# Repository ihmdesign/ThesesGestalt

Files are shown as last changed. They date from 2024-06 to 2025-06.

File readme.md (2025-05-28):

# **VibraForge: A Scalable Prototyping Toolkit For Creating Spatialized Vibrotactile Feedback Systems** #

This repository shares the open-source design files of the VibraForge toolkit, including mechanical design, electrical design, software design, and GUI editor. 

- Electrical Design
- GUI Editor
- Mechanical Design
- Software Design

If you are interested in using the toolkit and would like to get a development kit from us, please fill out [this Google Form](https://forms.gle/6aN7M9MWAf4sLqWE6)

## Quickstart Guidelines

If you already have the hardware dev kit shipped by the authors, it should contain a [quickstart guide](quickstart_guide.pdf) that you can easily follow.

Otherwise, you can follow step 1 & 2 to make the hardware yourself.

1. The `Electrical Design` folder has detailed descriptions of how to use the PCB design files to print the boards, and to program the boards with Arduino / MPLab X IDE.

2. The `Mechanical Design` folder contains all the CAD design files to print the parts.

3. Once all the hardware is setup, an easy place to start is to run the `Software_Design/Python_Server/Python_Test.py` program. It is used for simple test of the bluetooth control. You can manually input the vibration parameters in command lines. make sure the CHARACTERISTIC_UUID and CONTROL_UNIT_NAME are the same in control unit's Arduino code. To run the code:
```
Python Python_Test.py -uuid CUSTOM_UUID -name CONTROL_UNIT_NAME

default uuid = 'f22535de-5375-44bd-8ca9-d0ea9ff9e410'
default name = 'QT Py ESP32-S3'
```

4. If everything works well with `Python_Test.py`, then you can proceed to integrate the toolkit into your system! If you want to experiment with different vibration waveforms, you can use the `GUI_Editor` to try different waveforms, such as Sine, PWM, Triangle and Saw, etc. If you want to integrate the toolkit into Unity Engine developments, Use the `Software_design/Unity_Engine_API`. 

For detailed descriptions of each step, please refer to the `readme` files in the subfolders.

## Some Notes for Debugging

### Control Unit

Regarding the control unit, **the order of the four chain connectors** are shown in the figure. Also note that the USB port should be facing left. Putting it in the wrong direction may result in shorting the ESP32 MCU. 

If the MCU is not working for some unknown reasons, it might be a good idea to factory reset it following [this link](https://learn.adafruit.com/adafruit-qt-py-esp32-s3/factory-reset).

Control Unit Notes

### Vibration Unit

The unit address on each chain **starts from 0**. Maximum sixteen units can be connected to each chain. Therefore, the units on the first chain have address 0,1,2,...,15; The units on the second chain have address 16,17,...,31. When the programming pins are on the top, the input is on the left side, and the output is on the right side. Do not reverse the order, or the unit driver board might damage due to shortage.

Each vibration unit driver PCB has **two LEDs**. When the first LED lights up, it indicates that the board is correctly powered, when the second LED lights up, it indicates that it receives "Start" commands and should be vibrating. These two LEDs can be useful for checking MCU status during debugging.

Control Unit Notes

## Bug Report

If you identify any bug while using the toolkit, feel free to submit a new issue! The authors would try to resolve them ASAP :D

Have fun with the toolkit!

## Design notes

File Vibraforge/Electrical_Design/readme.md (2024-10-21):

# Electrical Engineering Section ##

The electrical engineering section includes PCB design files for control units and vibration units, and main programs for microcontrollers. All PCB design were initially finished in [EasyEDA](https://easyeda.com/) and later exported to different formats. If you want to manufacture the board with PCB factories such as [JLCPCB](https://jlcpcb.com/) or [PCBWay](https://www.pcbway.com/), simply use the Gerber files. If you want to revise the design, Import the design files into EasyEDA Editor or Altium Designer.

Control units include the large unit and the small unit, with different ESP32 microcontrollers. The large unit uses [Adafruit ESP32 Feather V2](https://learn.adafruit.com/adafruit-esp32-feather-v2). The small unit uses [Adafruit QT Py ESP32-S3](https://learn.adafruit.com/adafruit-qt-py-esp32-s3). The Arduino programs are very similar, except the software serial pins are configured differently.

Arduino Library Rrquirements:
- [Arduino ESP32 support](https://github.com/espressif/arduino-esp32)
- [SoftwareSerial for ESP32](https://github.com/plerup/espsoftwareserial)

Vibration units include LRA and VCA, all using the PIC16F18313 8-pin microcontroller. The main program is the same across all vibration units. To program / reprogram the MCU, you need to download the [MPLAB X IDE](https://www.microchip.com/en-us/tools-resources/develop/mplab-x-ide) and buy the  [MPLAB® PICkit™ 5 In-Circuit Debugger](https://www.microchip.com/en-us/development-tool/pg164150). import the main program into the IDE, connect the programming pins from the debugger to the top of the PCB board, following this [quickstart guideline](https://ww1.microchip.com/downloads/aemDocuments/documents/DEV/ProductDocuments/Brochures/MPLAB-PICkit-5-In-Circuit-Debugger-Quick-Start-Guide-50003478.pdf).

- Control_Unit
  - Large_Unit
  - Small_Unit
  - Main_Program_Arduino
    - BLE_peripheral_ESP32V2
    - BLE_peripheral_QTPyS3
- Vibration_Unit
  - Board_LRA
  - Board_VCA
  - Main_Program_MPLABXIDE
  - Schematic

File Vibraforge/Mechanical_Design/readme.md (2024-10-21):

# Mechanical Design

This folder contains CAD files for control units and vibration units. In our lab environment, parts are printed with PLA materials using 0.4mm nozzles on [Bambu Lab X1C 3D Printer](store.bambulab.com/collections/3d-printer/products/x1-carbon). Other printers with higher precision should also satisfy the requirements.

- Control_Unit_Large
- Control_Unit_Small
- Vibration_Unit_LRAX
- Vibration_Unit_LRAZ
- Vibration_Unit_VCA

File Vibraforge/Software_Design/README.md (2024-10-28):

# Software Design

## Python_Server

Python Lib Requirement:
- [BLEAK](https://bleak.readthedocs.io/en/latest/)

Three programs are available:
1. Python_Test.py

It is used for simple test of the bluetooth control. Users can manually input the vibration parameters in command lines. make sure the CHARACTERISTIC_UUID and CONTROL_UNIT_NAME are the same in control unit's Arduino code. To run the code:
```
Python Python_Test.py -uuid CUSTOM_UUID -name CONTROL_UNIT_NAME

default uuid = 'f22535de-5375-44bd-8ca9-d0ea9ff9e410'
default name = 'QT Py ESP32-S3'
```

2. Python_Play_Command.py

It reads commands from a data file, and plays vibrations accordingly. Data file are written in the following format:
```
{"time": 2.0, "addr": 1, "mode": 1, "duty": 0, "freq": 2}
{"time": 2.03, "addr": 1, "mode": 1, "duty": 1, "freq": 2}
{"time": 2.06, "addr": 1, "mode": 1, "duty": 2, "freq": 2}
```
To run the code:
```
Python Python_Play_Command.py -uuid CUSTOM_UUID -name CONTROL_UNIT_NAME -file FILENNAME

default uuid = 'f22535de-5375-44bd-8ca9-d0ea9ff9e410'
default name = 'QT Py ESP32-S3'
default file = 'command.json'
```

3. Python_Unity_Server.py

It receives vibration commands sent from Unity Engine through socket communication, converts the command format from JSON to bytearray, and sends the commands to the control unit. To run the code:

```
Python Python_Unity_Server.py -uuid CUSTOM_UUID -name CONTROL_UNIT_NAME -host HOST_IP -port PORT

default uuid = 'f22535de-5375-44bd-8ca9-d0ea9ff9e410'
default name = 'QT Py ESP32-S3'
default host = '127.0.0.1'
default port = 9051
```

## Unity_Engine_API

We also provide a Unity Engine API so that designers can directly make function calls to control vibrations. To get started, you can run the VibraForge_Plugin Unity project and see how the function calls are used to trigger vibrations when a ball collides with a wall. To integrate it into your own project,

1. Import `VibraForge_Plugin.unitypackage` as a custom package into an existing project.
2. Use the `VibraForgeSender` prefab to create a new gameobject, and configure the server IP address and port if needed. 
3. When Unity Engine events are triggered (e.g., OnTriggerEnter, OnTriggerExit, etc), call `VibraForge.SendCommand(addr, mode, duty, freq)` to send vibration commands.
4. Note: the `Python_Unity_Server.py` program is used to receive vibration commands through socket communication with Unity Engine APIs. it should be run before running the Unity program.

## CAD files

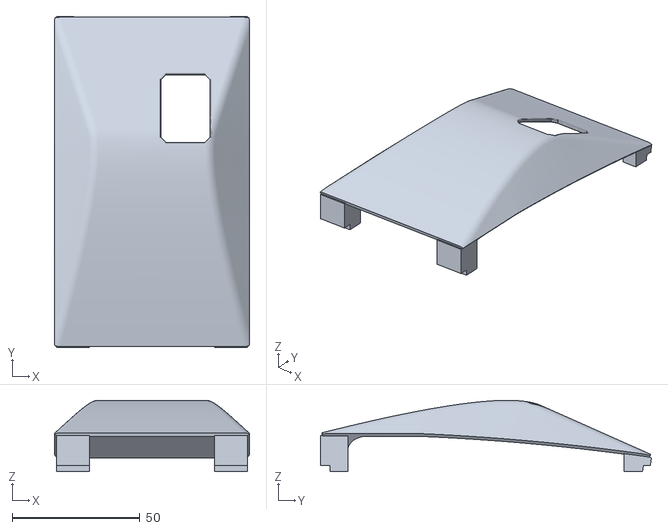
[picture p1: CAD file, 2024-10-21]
Vibraforge/Mechanical_Design/Control_Unit_Large/Cap.stl
76.4 x 129.4 x 27.9

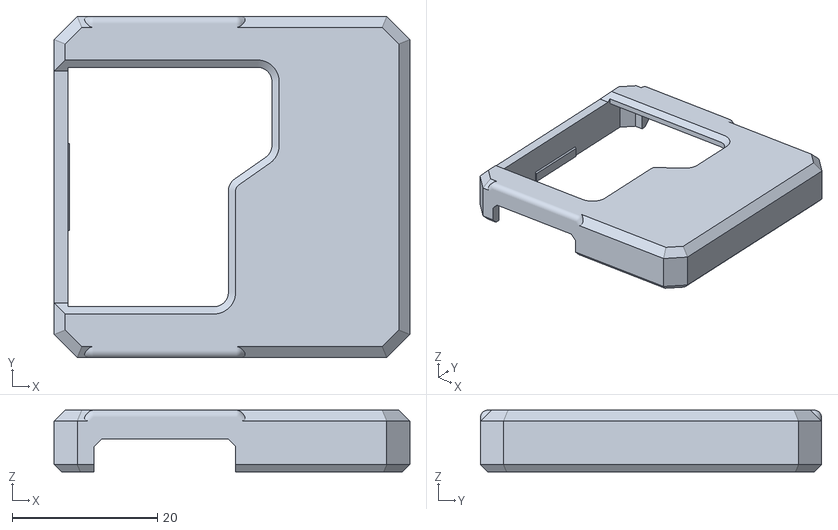
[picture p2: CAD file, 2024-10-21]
Vibraforge/Mechanical_Design/Control_Unit_Small/Cap.stl
49.0 x 47.0 x 8.50

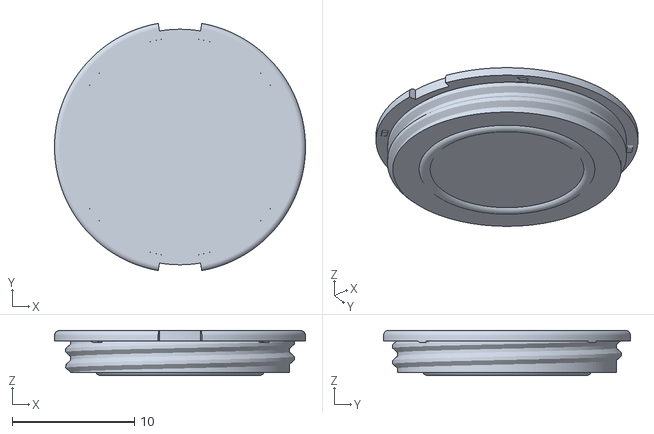
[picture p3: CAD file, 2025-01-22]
Vibraforge/Mechanical_Design/Vibration_Unit_LRAX/Cap.stl
20.5 x 20.2 x 3.70

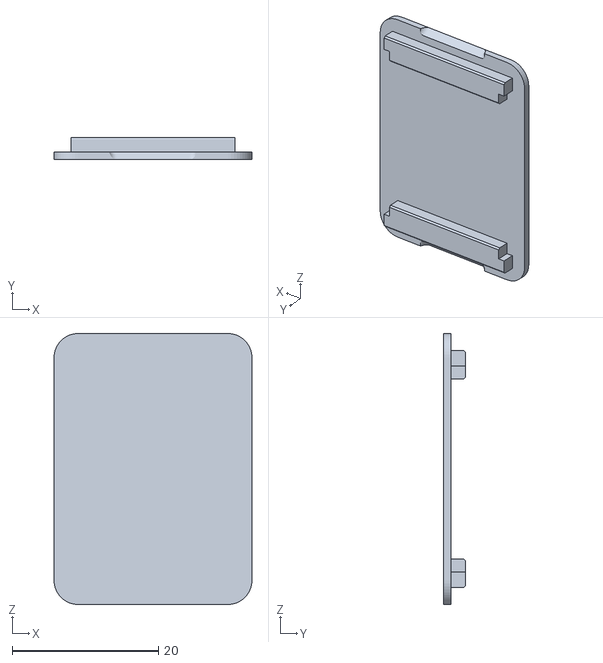
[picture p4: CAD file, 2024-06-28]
Vibraforge/Mechanical_Design/Vibration_Unit_VCA/Cap.stl
27.1 x 3.00 x 37.1

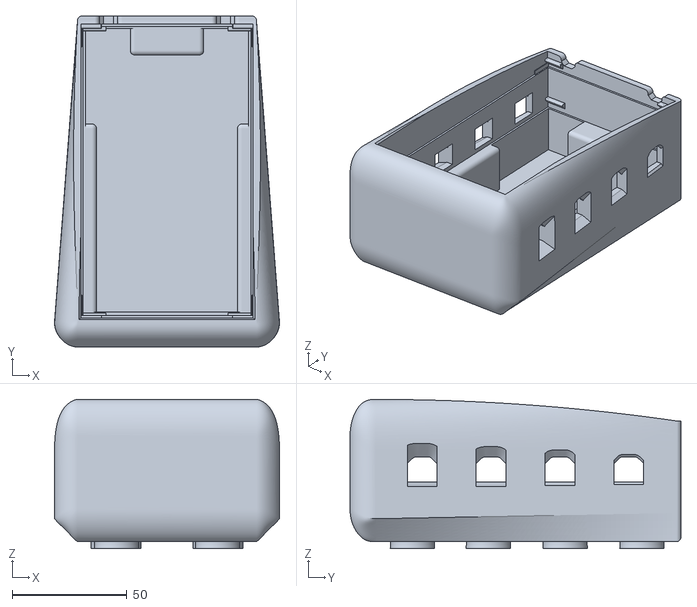
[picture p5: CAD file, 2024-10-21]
Vibraforge/Mechanical_Design/Control_Unit_Large/Enclosure.stl
98.1 x 144.2 x 65.0

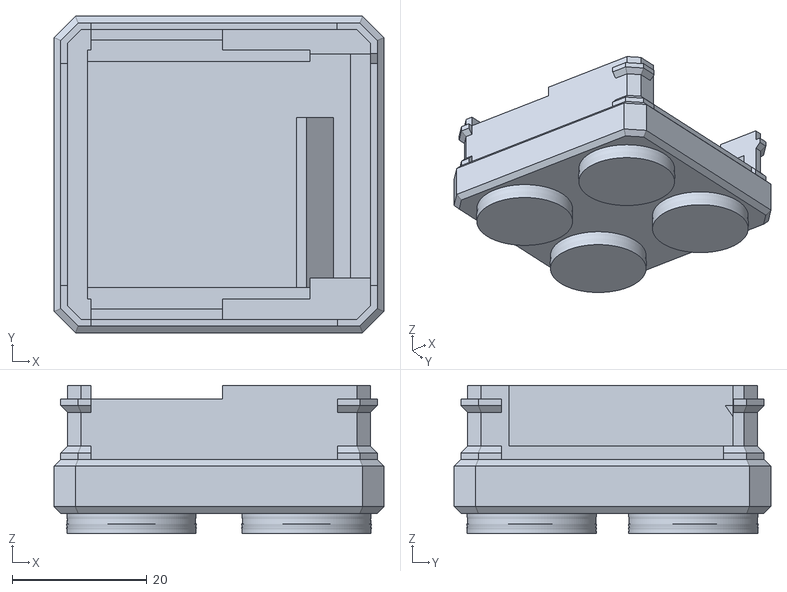
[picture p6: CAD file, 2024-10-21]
Vibraforge/Mechanical_Design/Control_Unit_Small/Enclosure.stl
49.0 x 47.0 x 22.0

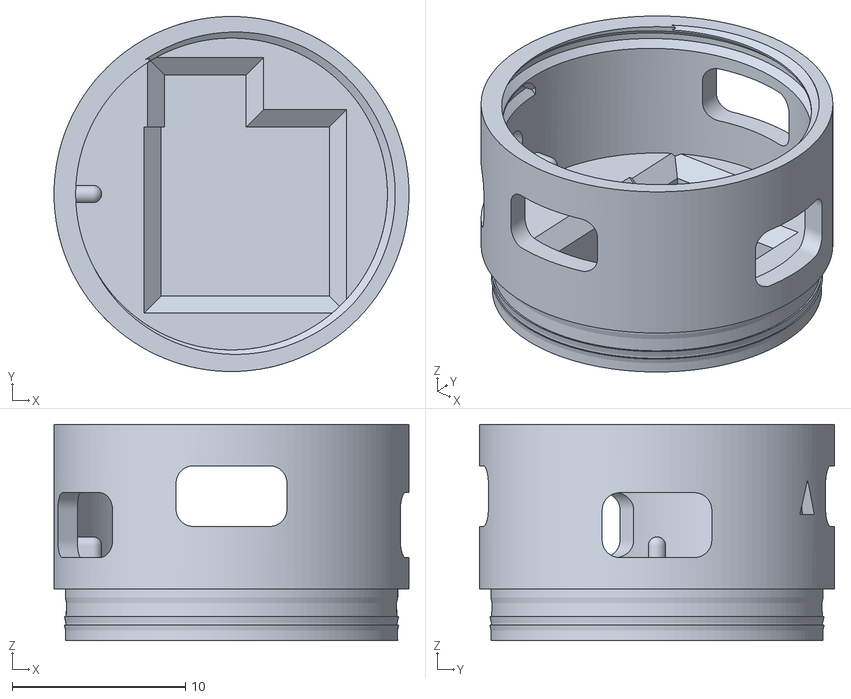
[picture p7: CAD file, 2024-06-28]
Vibraforge/Mechanical_Design/Vibration_Unit_LRAX/Enclosure.stl
20.5 x 20.5 x 12.5

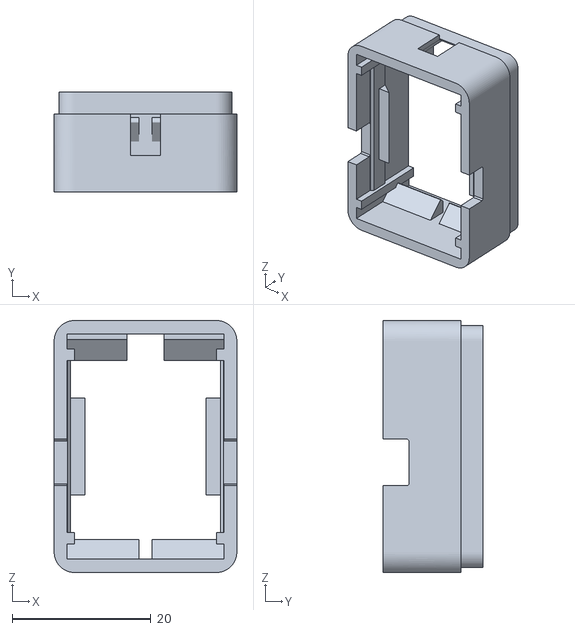
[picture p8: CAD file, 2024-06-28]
Vibraforge/Mechanical_Design/Vibration_Unit_VCA/Enclosure.stl
26.4 x 14.5 x 36.4

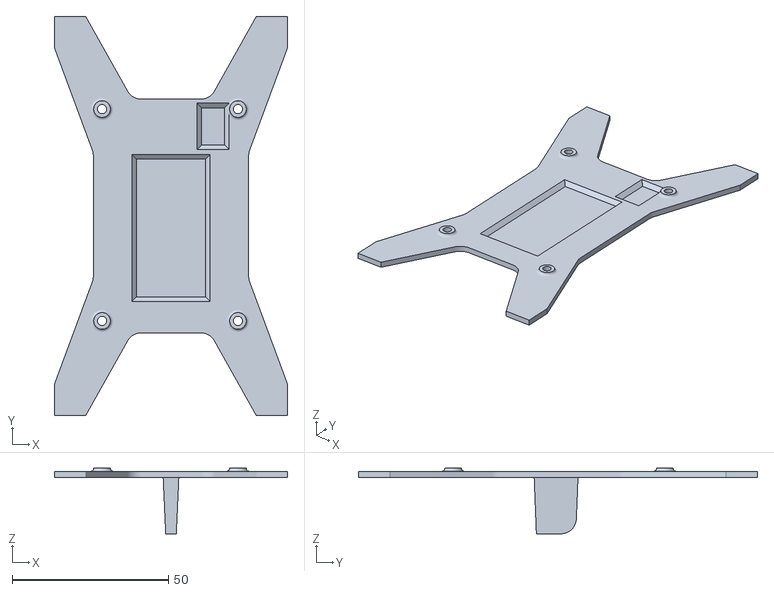
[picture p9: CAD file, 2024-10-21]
Vibraforge/Mechanical_Design/Control_Unit_Large/Mount.stl
74.5 x 127.5 x 21.0

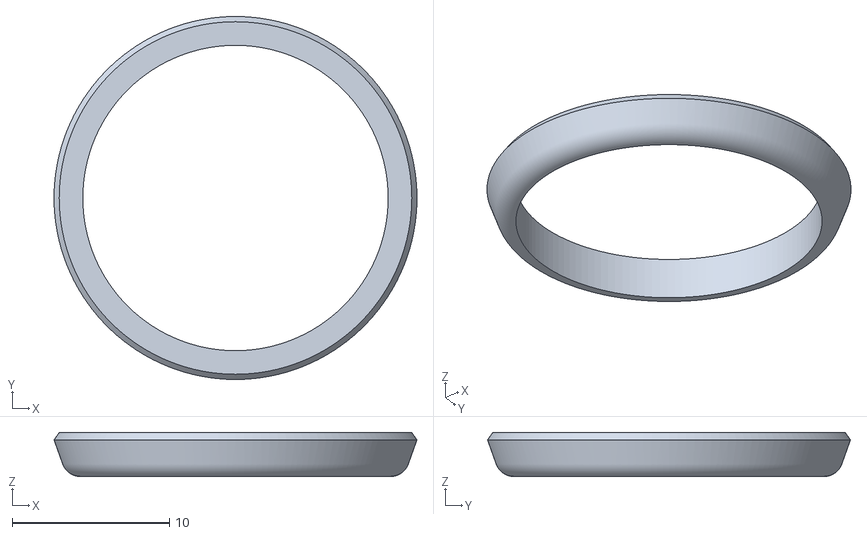
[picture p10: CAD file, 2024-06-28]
Vibraforge/Mechanical_Design/Vibration_Unit_LRAX/Ring.stl
23.1 x 23.1 x 2.80

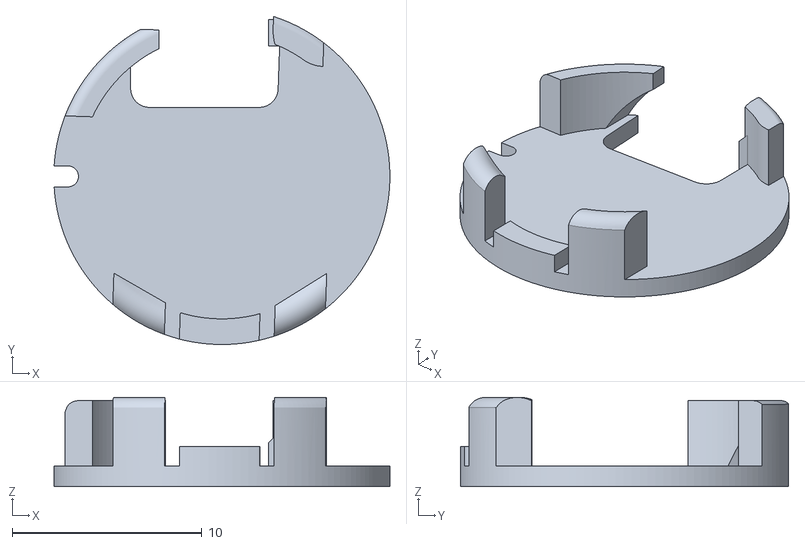
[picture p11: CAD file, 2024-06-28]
Vibraforge/Mechanical_Design/Vibration_Unit_LRAZ/Mount.stl
17.7 x 17.3 x 4.69

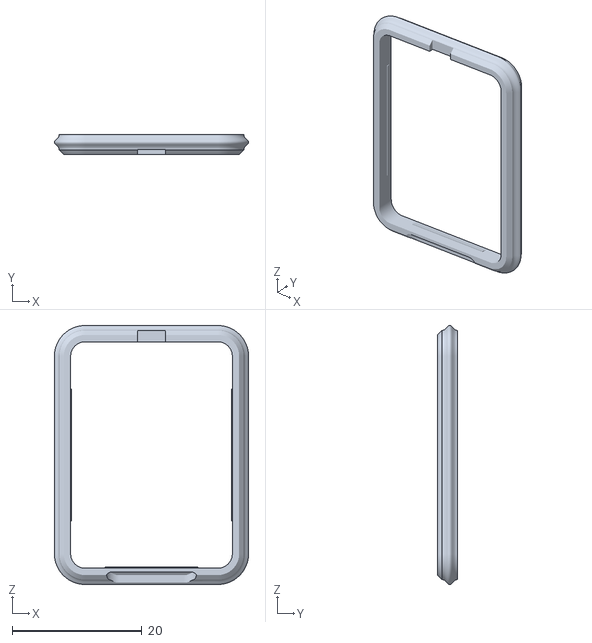
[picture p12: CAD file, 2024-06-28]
Vibraforge/Mechanical_Design/Vibration_Unit_VCA/Ring.stl
30.0 x 3.14 x 40.0

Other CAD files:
Vibraforge/Mechanical_Design/Vibration_Unit_LRAZ/Enclosure.stl

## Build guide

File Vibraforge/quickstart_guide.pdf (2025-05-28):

# VibraForge Dev Kit v1

What’s Inside? | Quick Start Guide:

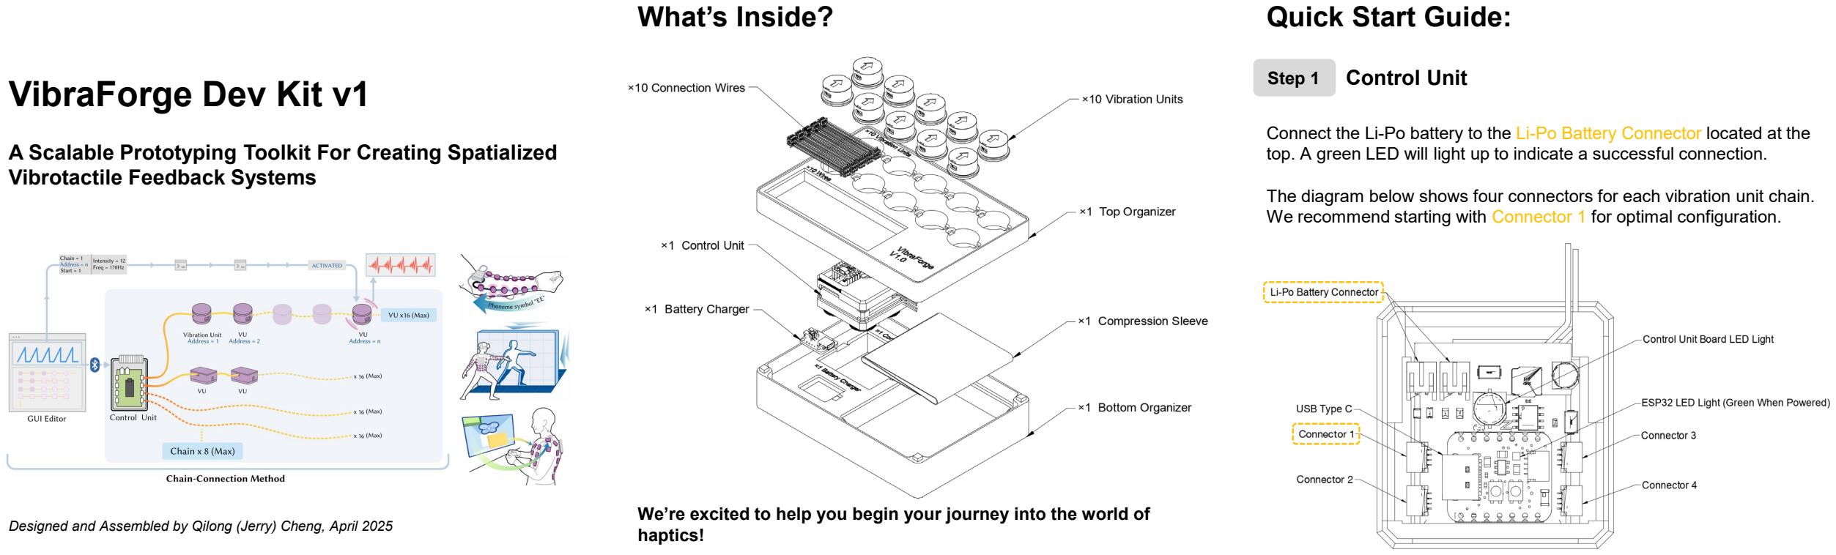
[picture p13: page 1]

### A Scalable Prototyping Toolkit For Creating Spatialized Vibrotactile Feedback Systems

We’re excited to help you begin your journey into the world of haptics!

Connect the Li-Po battery to the Li-Po Battery Connector located at the top. A green LED will light up to indicate a successful connection.

The diagram below shows four connectors for each vibration unit chain. We recommend starting with Connector 1 for optimal configuration.

Step 1

Designed and Assembled by Qilong (Jerry) Cheng, April 2025

### Control Unit

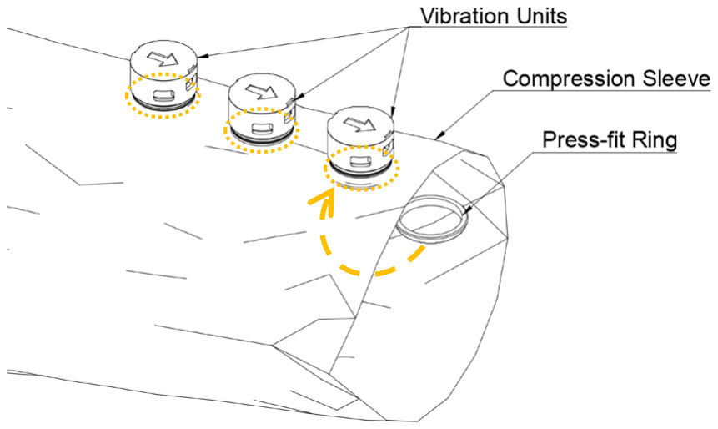
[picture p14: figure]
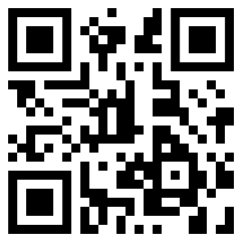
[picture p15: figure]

Once the hardware is setup, you can play vibrations using software from the GitHub Repo https://github.com/huangbj16/VibraForge
An easy place to start is to run
Software_Design/Python_Server/Python_Test.py
- pip install bleak
- python Python_Test.py
If you prefer using GUI, try GUI_Editor/main app/app.py
- pip install PyQt6 numpy matplotlib scipy bleak
- python app.py
Step 2

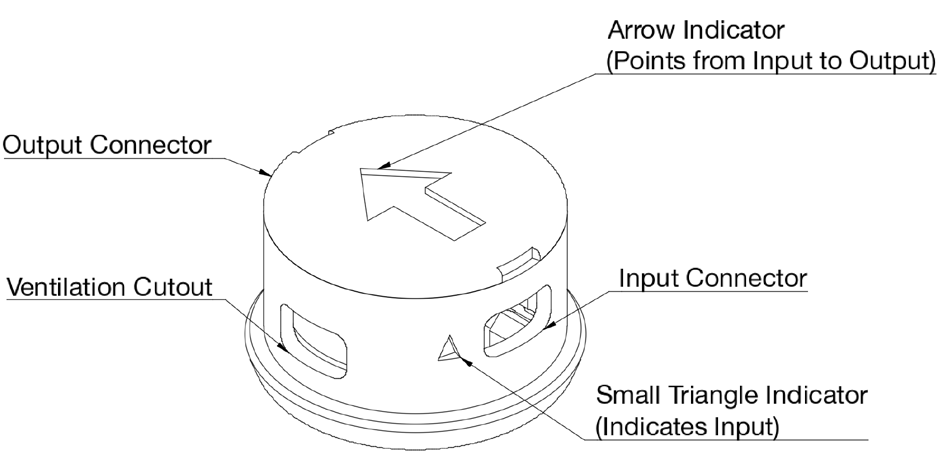
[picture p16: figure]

### Step 3 Connect Them Together

Vibration Units | Step 4 Attach Vibration Units to the Sleeve Slide the vibration unit onto the compression sleeve and place the press- fit ring under. Press the components together until they securely lock onto the sleeve.

Each chain supports up to 16 units. The unit address on each chain starts from 0.

For example, the units on the first chain have address 0,1,2,...,15.

### Step 5 Have Fun!

# Useful Links:

A full walkthrough video for the assembly: https://www.youtube.com/watch?v=Ji4QbBA8m8U

Open-source GitHub repository: https://github.com/huangbj16/VibraForge

If you have any other questions for the toolkit or potential collaborations, feel free to email me!

### Contact:

Bingjian Huang

bj.huang@mail.utoronto.ca
+1 617-216-8865
https://huangbj16.github.io

The arrow → on the cap
indicates the connecting
direction from input to
output.
Do not reverse the
direction, or the unit
driver board might be
damaged due to short
circuit.

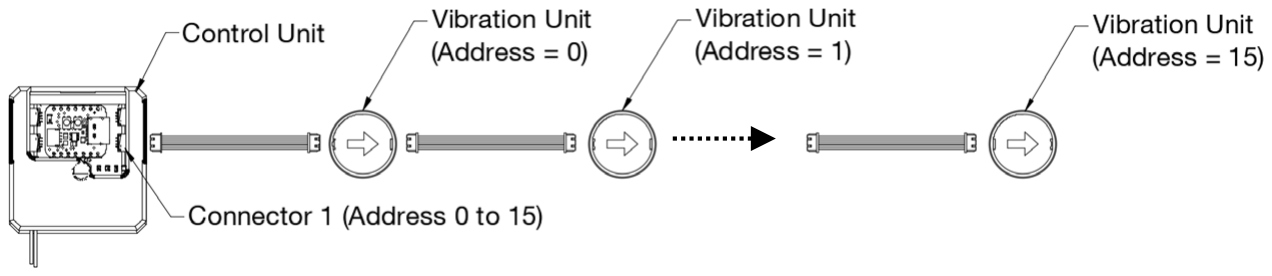
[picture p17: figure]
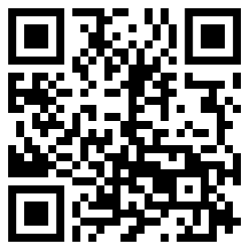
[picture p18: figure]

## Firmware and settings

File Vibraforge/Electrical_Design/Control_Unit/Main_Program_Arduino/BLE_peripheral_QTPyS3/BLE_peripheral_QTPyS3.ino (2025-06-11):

#include <BLEDevice.h>
#include <BLEUtils.h>
#include <BLEServer.h>
#include <BLEClient.h>
#include <ArduinoJson.h>
#include <Adafruit_NeoPixel.h>
#include <SoftwareSerial.h>

// See the following for generating UUIDs:
// https://www.uuidgenerator.net/

#define SERVICE_UUID        "f10016f6-542b-460a-ac8b-bbb0b2010599"
#define CHARACTERISTIC_UUID "f22535de-5375-44bd-8ca9-d0ea9ff9e410"
//#define CURRENTSENSING_UUID "640b8bf5-3c88-44f6-95e0-f5813b390d73"
BLECharacteristic *csCharacteristic;

bool deviceConnected = false;

Adafruit_NeoPixel strip(1, PIN_NEOPIXEL, NEO_GRB + NEO_KHZ800);

const int subchain_pins[4] = {18, 17, 9, 8};
const int subchain_num = 4;
uint32_t colors[5];
int color_num = 5;
int global_counter = 0;

EspSoftwareSerial::UART serial_group[4];

class MyCharacteristicCallbacks: public BLECharacteristicCallbacks {
  void onWrite(BLECharacteristic *pCharacteristic) {
      String value = pCharacteristic->getValue();
      if (value.length() % 3 == 0) {  // Ensure the length is a multiple of 3 bytes
          unsigned long timestamp = millis(); // Get current time in milliseconds
          Serial.print("Timestamp: ");
          Serial.print(timestamp);
          Serial.print(" ms, Data = ");
          Serial.print(value.length());
          Serial.print(" bytes, # = ");
          Serial.println(++global_counter);
  
          for (int i = 0; i < value.length(); i += 3) {
              uint8_t byte1 = value[i];
              uint8_t byte2 = value[i+1];
              uint8_t byte3 = value[i+2];
  
              if (byte1 == 0xFF) continue; // Skip if the first byte of the command is 0xFF
  
              int serial_group_number = (byte1 >> 2) & 0x0F;
              int is_start = byte1 & 0x01;
              int addr = byte2 & 0x3F;
              int duty = (byte3 >> 3) & 0x0F;
              int freq = (byte3 >> 1) & 0x03;
              int wave = byte3 & 0x01;
  
              // Print received values for debugging
              // Uncomment the following lines if you want to output the values for debugging purposes
              
              Serial.print("Received: ");
              Serial.print("SG: "); Serial.print(serial_group_number);
              Serial.print(", Mode: "); Serial.print(is_start);
              Serial.print(", Addr: "); Serial.print(addr);
              Serial.print(", Duty: "); Serial.print(duty);
              Serial.print(", Freq: "); Serial.print(freq);
              Serial.print(", Wave: "); Serial.println(wave);
              
              
              sendCommand(serial_group_number, addr, is_start, duty, freq, wave);
          }
      }
      else{
          unsigned long timestamp = millis(); // Get current time in milliseconds
          Serial.print("Timestamp: ");
          Serial.print(timestamp);
          Serial.print(" ms, Data = ");
          Serial.print(value.length());
          Serial.print(", WRONG LENGTH!!!!!!!!!!!!!!!!");
      }
  }


    /* command format
        command = {
            'addr':motor_addr,
            'mode':start_or_stop,
            'duty':3, # default
            'freq':2, # default
            'wave':0, # default
        }
    */
    void sendCommand(int serial_group_number, int motor_addr, int is_start, int duty, int freq, int wave) {
//      uint8_t message = motor_addr;
//      serial_group[serial_group_number].write(message);
//      return;
      if (is_start == 1) { // Start command, two bytes
        uint8_t message[2];
        message[0] = (motor_addr << 1) | is_start;
        message[1] = 0x80 | (duty << 3) | (freq << 1) | wave;
        serial_group[serial_group_number].write(message, 2);
      } else { // Stop command, only one byte
        uint8_t message = (motor_addr << 1) | is_start;
        serial_group[serial_group_number].write(&message, 1);
      }
    }
};

class MyServerCallbacks: public BLEServerCallbacks {
    void onConnect(BLEServer* pServer, esp_ble_gatts_cb_param_t *param){
        Serial.println("connected!");
        Serial.println(BLEDevice::toString().c_str());
        char bda_str[18];
        sprintf(bda_str, "%02X:%02X:%02X:%02X:%02X:%02X", param->connect.remote_bda[0], param->connect.remote_bda[1], param->connect.remote_bda[2], param->connect.remote_bda[3], param->connect.remote_bda[4], param->connect.remote_bda[5]);
        Serial.println("Device connected with Address: " + String(bda_str));
        pServer->updateConnParams(param->connect.remote_bda, 0, 0, 0, 100);
        deviceConnected = true;
    }

    void onDisconnect(BLEServer* pServer) {
      Serial.println("disconnected!");
      delay(500);
      deviceConnected = false;
      BLEDevice::startAdvertising();
    }
};


void setup() {
  Serial.begin(500000);//even parity check
  //  pinMode(8, OUTPUT);
  //  pinMode(7, INPUT);
  //  Serial1.begin(115200, SERIAL_8E1);// Hardware Serial
  Serial.print("number of hardware serial available: ");
  Serial.println(SOC_UART_NUM);
  for (int i = 0; i < subchain_num; ++i) {
    Serial.print("initialize uart on ");
    Serial.println(subchain_pins[i]);
    serial_group[i].begin(115200, SWSERIAL_8E1, -1, subchain_pins[i], false);
    serial_group[i].enableIntTx(false);
    if (!serial_group[i]) { // If the object did not initialize, then its configuration is invalid
      Serial.println("Invalid EspSoftwareSerial pin configuration, check config");
    }
    delay(200);
  }
  Serial.println("Starting BLE work!");

  //setup LED
  pinMode(LED_BUILTIN, OUTPUT);
  digitalWrite(LED_BUILTIN, HIGH);
  pinMode(2, OUTPUT);
  digitalWrite(2, HIGH);
  strip.begin();
  strip.setBrightness(20);
  colors[0] = strip.Color(0, 255, 0);
  strip.setPixelColor(0, colors[0]);
  strip.show();

  //BLE setup
  BLEDevice::init("QT Py ESP32-S3");
  BLEServer *pServer = BLEDevice::createServer();
  pServer->setCallbacks(new MyServerCallbacks());
  BLEDevice::setMTU(128);
  BLEService *pService = pServer->createService(SERVICE_UUID);
  BLECharacteristic *pCharacteristic = pService->createCharacteristic(
                                         CHARACTERISTIC_UUID,
                                         BLECharacteristic::PROPERTY_READ |
                                         BLECharacteristic::PROPERTY_WRITE
                                       );
  pCharacteristic->setValue("0");
  pCharacteristic->setCallbacks(new MyCharacteristicCallbacks());
//  csCharacteristic = pService->createCharacteristic(
//                       CURRENTSENSING_UUID,
//                       BLECharacteristic::PROPERTY_READ
//                     );
//  csCharacteristic->setValue("0");

  pService->start();

  // BLEAdvertising *pAdvertising = pServer->getAdvertising();  // this still is working for backward compatibility
  BLEAdvertising *pAdvertising = BLEDevice::getAdvertising();
  pAdvertising->addServiceUUID(SERVICE_UUID);
  pAdvertising->setScanResponse(true);
//  pAdvertising->setMinPreferred(0x00);
//  pAdvertising->setMaxPreferred(0x00);
  BLEDevice::startAdvertising();
  Serial.println("Characteristic defined! Now you can read it in your phone!");

  //actuator pin setup
  //  for (int i=0; i<subchain_num; ++i){
  //    pinMode(subchain_pins[i], OUTPUT);
  //    digitalWrite(subchain_pins[i], LOW);
  //  }
//  pinMode(39, INPUT);
}

void loop() {
  // put your main code here, to run repeatedly:
//  csCharacteristic->setValue(String(analogRead(39)).c_str());
//  delay(1000);
}

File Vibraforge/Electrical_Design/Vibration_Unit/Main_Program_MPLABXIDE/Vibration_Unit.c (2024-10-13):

/* 
 * File:   main.c
 * Author: MasonC
 *
 * Created on November 8, 2022, 10:19 PM
 */

#include <stdio.h>
#include <stdlib.h>




// PIC16F18313 Configuration Bit Settings

// 'C' source line config statements

// CONFIG1
#pragma config FEXTOSC = OFF    // FEXTOSC External Oscillator mode Selection bits (Oscillator not enabled)
#pragma config RSTOSC = HFINT32  // Power-up default value for COSC bits (HFINTOSC (1MHz))
#pragma config CLKOUTEN = OFF   // Clock Out Enable bit (CLKOUT function is disabled; I/O or oscillator function on OSC2)
#pragma config CSWEN = OFF      // Clock Switch Enable bit (The NOSC and NDIV bits cannot be changed by user software)
#pragma config FCMEN = OFF      // Fail-Safe Clock Monitor Enable (Fail-Safe Clock Monitor is disabled)

// CONFIG2
#pragma config MCLRE = ON       // Master Clear Enable bit (MCLR/VPP pin function is MCLR; Weak pull-up enabled )
#pragma config PWRTE = OFF      // Power-up Timer Enable bit (PWRT disabled)
#pragma config WDTE = ON       // Watchdog Timer Enable bits (WDT disabled; SWDTEN is ignored)
#pragma config LPBOREN = OFF    // Low-power BOR enable bit (ULPBOR disabled)
#pragma config BOREN = OFF      // Brown-out Reset Enable bits (Brown-out Reset disabled)
#pragma config BORV = LOW       // Brown-out Reset Voltage selection bit (Brown-out voltage (Vbor) set to 2.45V)
#pragma config PPS1WAY = OFF    // PPSLOCK bit One-Way Set Enable bit (The PPSLOCK bit can be set and cleared repeatedly (subject to the unlock sequence))
#pragma config STVREN = ON      // Stack Overflow/Underflow Reset Enable bit (Stack Overflow or Underflow will cause a Reset)
#pragma config DEBUG = OFF      // Debugger enable bit (Background debugger disabled)

// CONFIG3
#pragma config WRT = OFF        // User NVM self-write protection bits (Write protection off)
#pragma config LVP = OFF         // Low Voltage Programming Enable bit (Low voltage programming enabled. MCLR/VPP pin function is MCLR. MCLRE configuration bit is ignored.)

// CONFIG4
#pragma config CP = OFF         // User NVM Program Memory Code Protection bit (User NVM code protection disabled)
#pragma config CPD = OFF        // Data NVM Memory Code Protection bit (Data NVM code protection disabled)

// #pragma config statements should precede project file includes.
// Use project enums instead of #define for ON and OFF.
#include <xc.h>
#include <stdint.h>
#include <stdlib.h>
#define _XTAL_FREQ  32000000     // Set clock frequency 

uint8_t buffer = 0;//uart recv buffer

uint8_t duty_index = 7; // 0-15 maps to PWM duty cycle 0-100%;
uint8_t freq_index = 3; // 0-7 maps to frequency {123, 145, 170, 200, 235, 275, 322, 384} Hz;

uint8_t PR_val[] = {127, 107, 91, 78, 66, 56, 48, 40}; // PR2 values for frequencies;

// Index into sine table
uint8_t index = 0;
uint8_t state = 0; //is the board being addressed by the controller

void init_ccp_cwg(void) {
    // Set PA0, PA1 Pin as output
    TRISA0 = 1;//first set the flag to disable PA0 and PA1 outputs
    TRISA1 = 1;
    ANSELA = 0; // all digital
    WPUA = 0; // weak pullup
    //RA1PPS = 12; // Output CCP1 to RA1
    RA1PPS = 0b01000; //get cwg1a
    RA0PPS = 0b01001;//get cwg1b
    // Set CCP1CON register to PWM mode
    CCP1CON = 0b10011111;//FMT = 1
    CCP1IE = 1;
    CCP1IF = 1;
    // Enable Global Interrupts
    GIE = 1;
    
    // Enable Peripheral Interrupts
    PEIE = 1;
    TMR2IE = 1; //enable interrupt on timer2
    // Set PR2 with appropriate PWM period
    
    // Set Timer2 Control Register
    T2CON = 0b00000010; // Timer 2 PS1/16 setting
    PR2 = PR_val[freq_index];
    
    //set cwg
  
    CWG1CON0 = 0b01000100;//half bridge, disable
    CWG1CON1 = 0;//A--non-invert, B--invert, C--non-invert, D--invert
    CWG1DAT = 0b00000011;//set data input to ccp1
    CWG1AS0 = 0b01111000;//disable autoshutdown, all 0 when shutdown occurs
    CWG1DBR = 0b0;
    CWG1DBF = 0b0;
    CWG1CLKCON = 1; //select hfint clk
    CWG1CON0bits.EN = 1;
    __delay_us(100);
}

void usart_init() {
    TRISA5 = 1; //port 5 as RXinput
    TRISA2 = 1; //port 2 as TXout
    ANSELA = 0;
    RXPPS = 0b00101; //port5 RX
    RA2PPS = 0b10100; //port2 TX

    RC1STA = 0b10010000; // 8 bit continuous reception CREN = 1 SPEN = 1
    TX1STA = 0b00100100; // Asynchronous reception High Baud Rate selection BRGH = 1  TXEN = 1; //transmit enable //async mode
    BAUD1CON = 0b00001000; // 16 bit SPBRG   BRG16 = 1
    SP1BRGH = 0;
    SP1BRGL = 68; // 115.2k baud rate
    TX9 = 1; //enable 9bit transmission
    RX9 = 1; //enable 9-bit recv
    RCIE = 1; //receive interrupt enable
    //IDLEN = 1; // Idle inhibits the CPU clk

    __delay_us(100); //wait for set up

}
uint8_t make_addr_byte(uint8_t start, uint8_t addr){
    //make the first, address byte for transmission
    uint8_t addr_byte = 0;
    addr_byte |= (start & 0b1);
    addr_byte |= (addr << 1);
   
    return addr_byte;
}
uint8_t getParity(uint8_t n)
{ //return the parity of n. if odd, return 1, even, return 0
    uint8_t parity = 0;
    while (n)
    {
        parity = !parity;
        n = n & (n - 1);
    }
    return (parity & 0b1);
}

void UART_Write(uint8_t data) {
    while(!TRMT){};
    
    TX9D = (getParity(data) & 0b1);
    TX1REG = data;
    
}
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

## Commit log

2024-06-28 early version
    [Black_backpack_cover_1.stl, Black_backpack_cover_2.stl, White_backpack_battery_holder.stl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]
2024-10-20 add documentation v0.1
    [Black_backpack_cover_1.stl, Black_backpack_cover_2.stl, Board_LRA_Altium.pcbdoc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]
2025-01-22 update cap STL files
    [Cap.stl]
2025-06-11 temporarily reduce refresh rate in GUI to enhance stability
    [BLE_peripheral_QTPyS3.ino]
2025-06-17 Ajout dossier
    [Board_LRA_Altium.pcbdoc, Board_Large_Unit_Altium.pcbdoc, Board_Small_Unit_Altium.pcbdoc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]
